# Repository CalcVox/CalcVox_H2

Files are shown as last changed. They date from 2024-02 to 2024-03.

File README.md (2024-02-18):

# CalcVox H2 Schematics and PCB Files

[View in Browser](https://kicanvas.org/?github=https://github.com/CalcVox/CalcVox_H2)

This is part of the [CalcVox](https://calcvox.org) Project. I am using KiCAD for these but I have included images below. 

I am trying to make these accessible but am struggling. If you know how to please open an issue.

## Parts

* [Teensy 4.1](https://www.pjrc.com/store/teensy41.html)
* [Seed Studio XIAO ESP32S3](https://www.seeedstudio.com/XIAO-ESP32S3-p-5627.html)
* [Adafruit UDA1334A I2S DAC (using a knockoff from amazon)](https://www.amazon.com/AITRIP-CJMCU-1334-UDA1334A-Decoder-Arduino/dp/B09DG21C7G)
* [Adafruit MiniBoost](https://www.adafruit.com/product/4654)
* [Rotary Encoder](https://www.sparkfun.com/products/9117)
* [Speaker (can use any)](https://www.adafruit.com/product/1891)
* 102AH 2.1mm Barrel Jack
* 3524N 3.5mm Audio Jack
* Piezo Buzzer
* Standard footprint buttons
* Various resistors
* Diodes

## Schematic

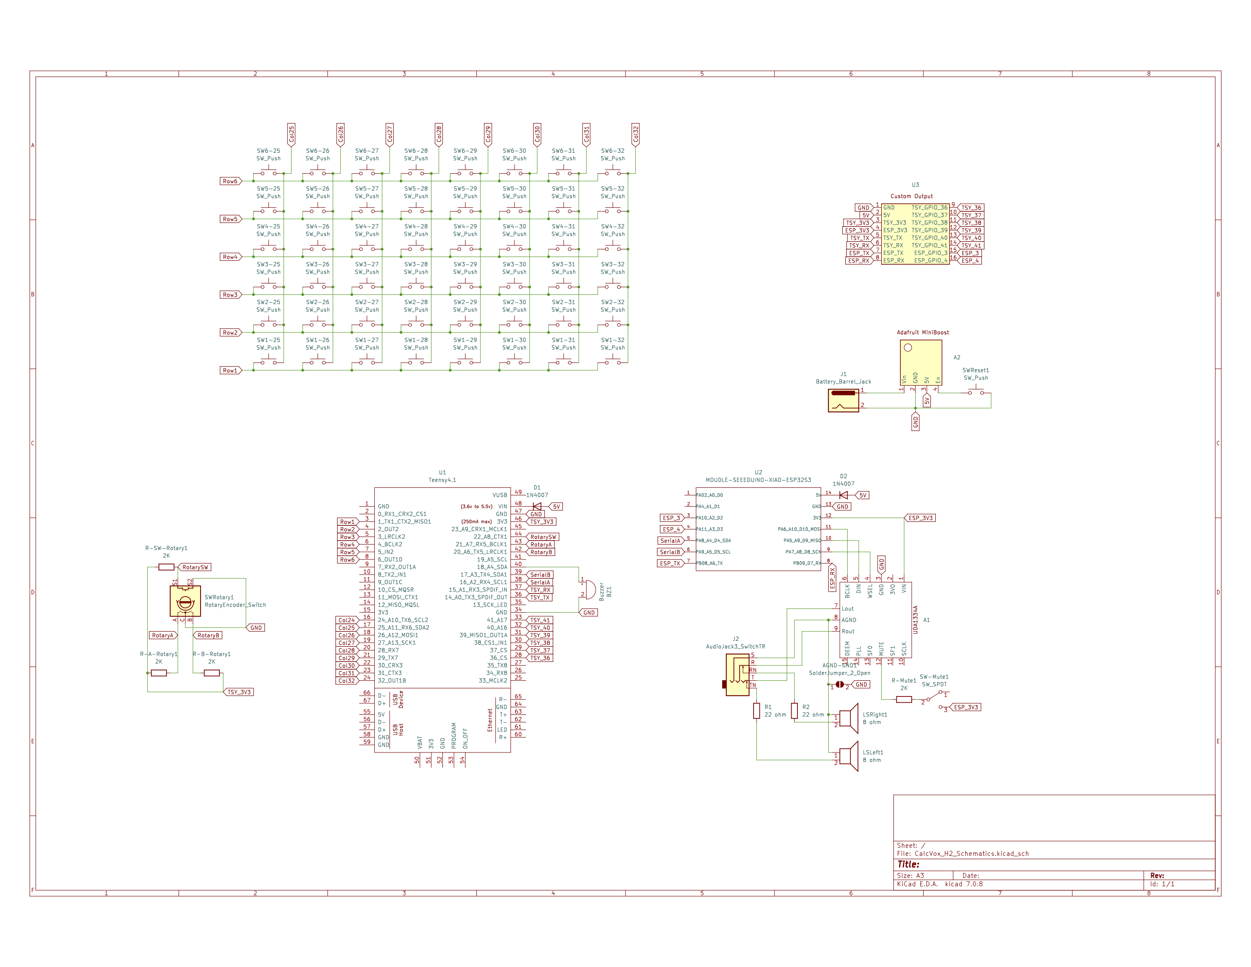
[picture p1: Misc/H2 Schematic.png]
H2 Schematic


## PCB

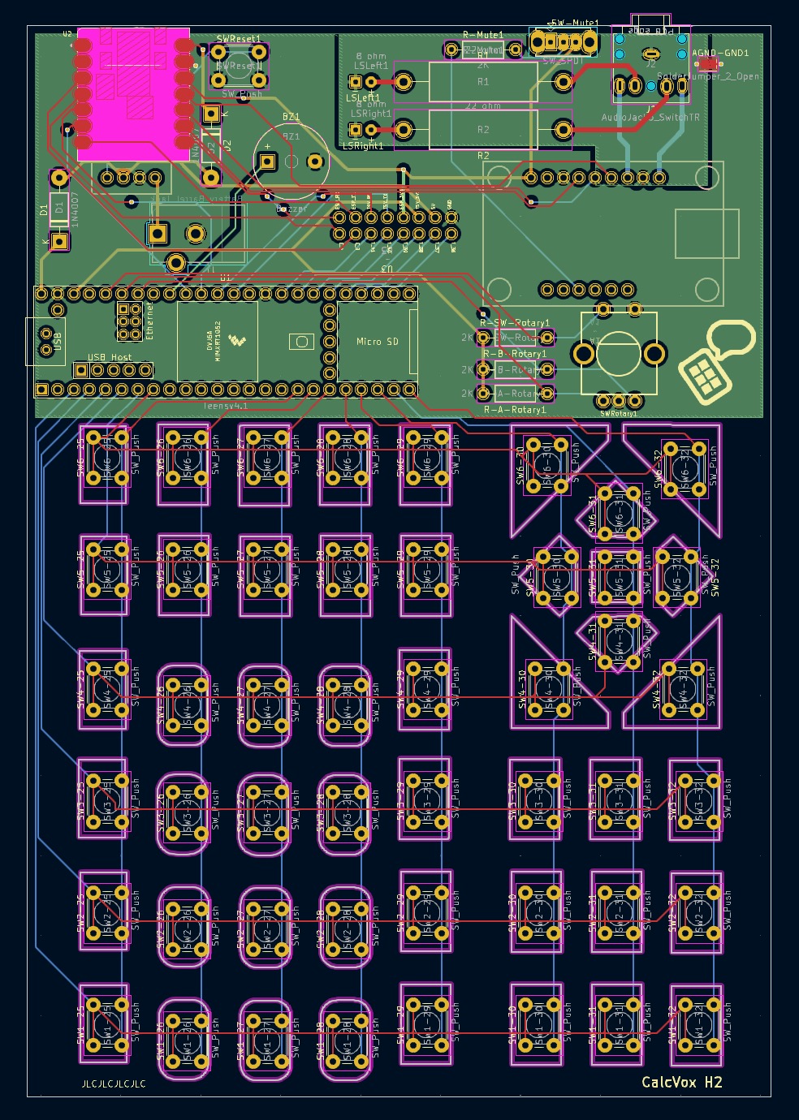
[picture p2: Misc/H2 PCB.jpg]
H2 PCB


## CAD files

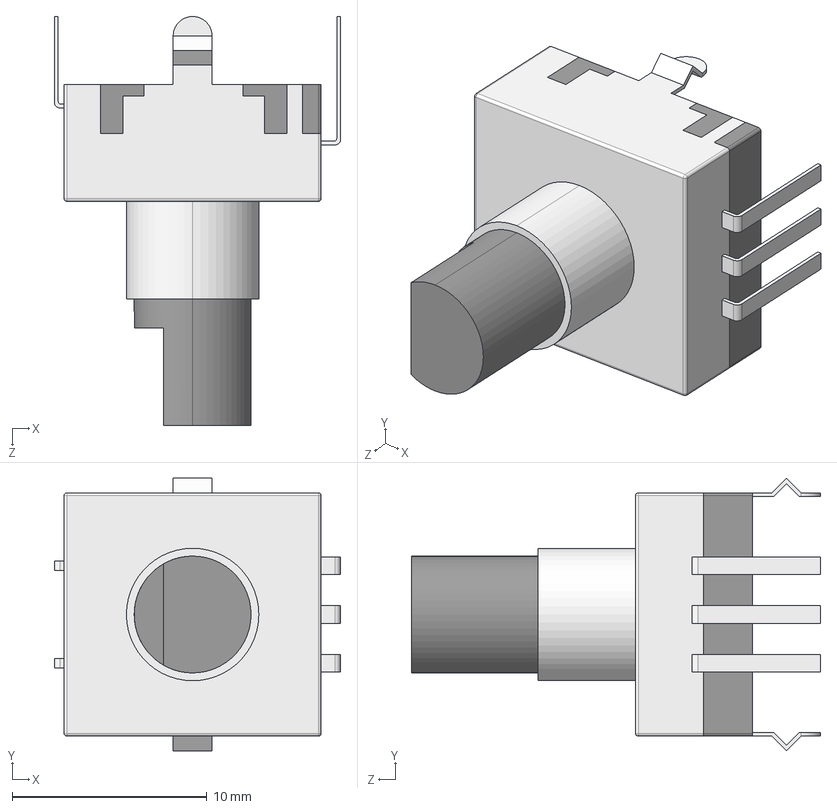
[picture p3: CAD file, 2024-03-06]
RE130F-41-175F-12P.stp
14.7 x 14.0 x 21.0 mm

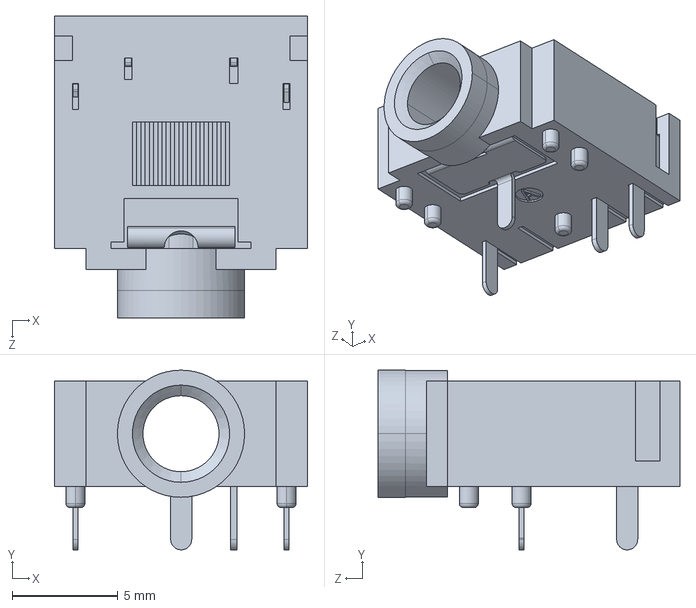
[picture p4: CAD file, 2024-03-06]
CUI_DEVICES_SJ1-3524N.step
12.0 x 8.51 x 14.3 mm

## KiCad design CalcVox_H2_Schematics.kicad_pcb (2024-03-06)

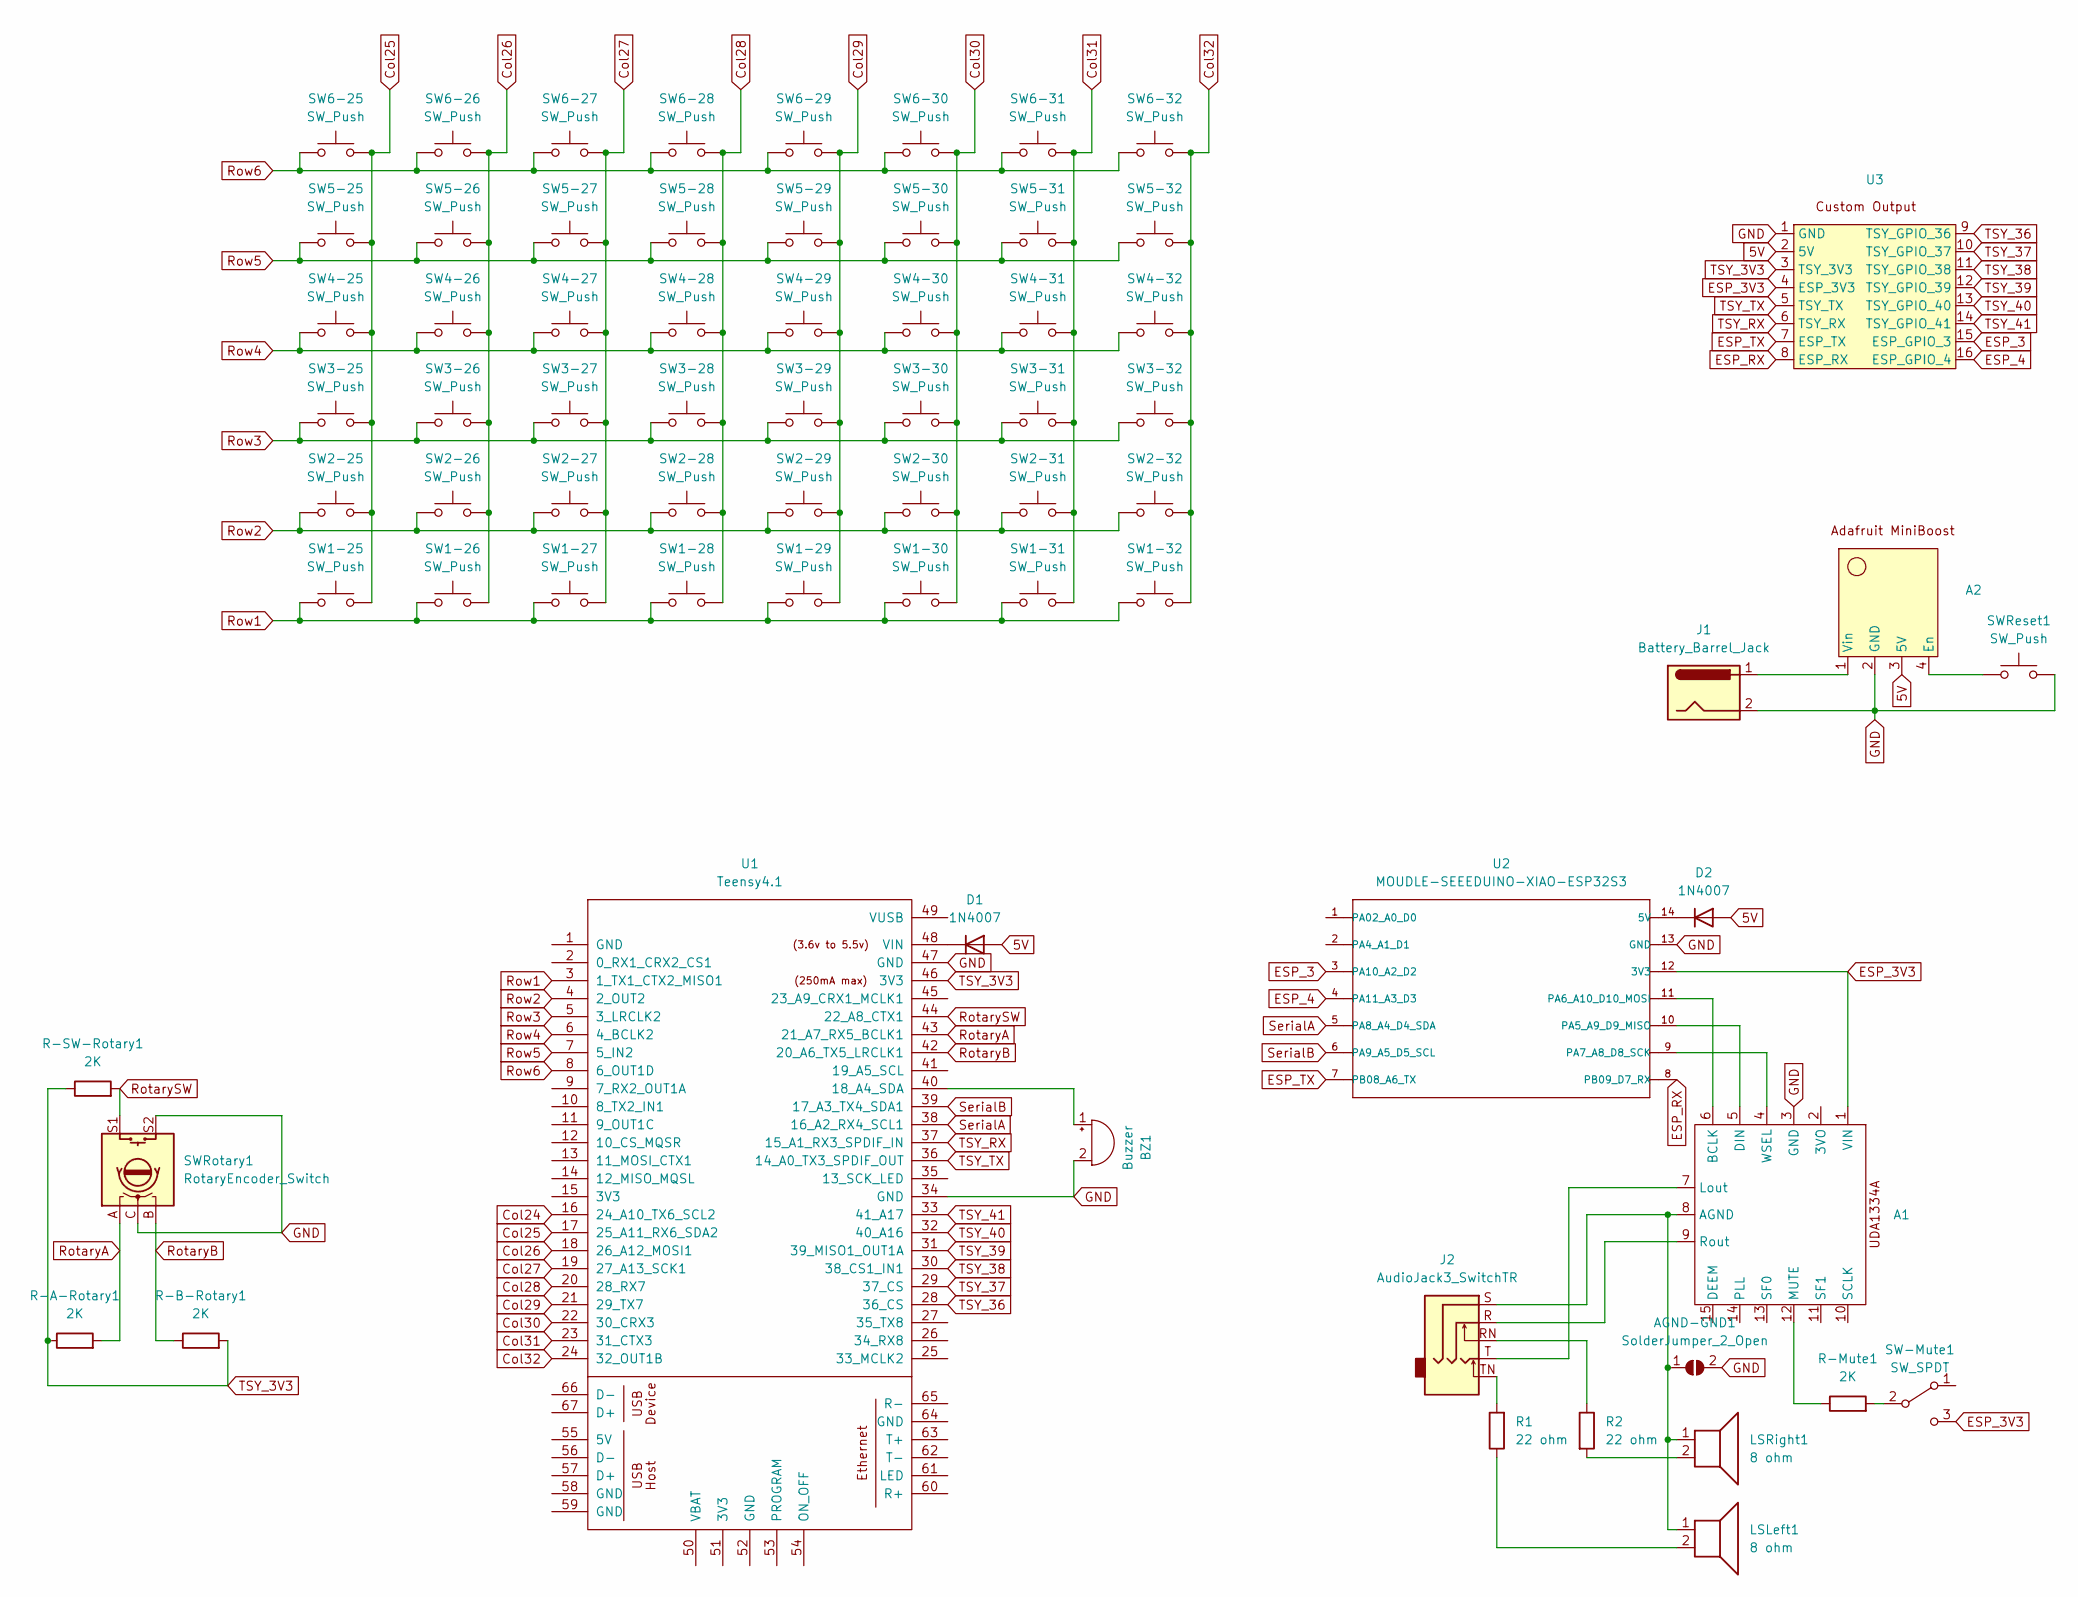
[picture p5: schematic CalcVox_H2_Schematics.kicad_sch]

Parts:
A1: Adafruit UDA1334A I2S Stereo DAC
A2: Adafruit MiniBost
AGND-GND1: SolderJumper_2_Open; SolderJumper-2_P1.3mm_Open_TrianglePad1.0x1.5mm
BZ1: Buzzer; Buzzer_12x9.5RM7.6
D1, D2: 1N4007; D_DO-41_SOD81_P10.16mm_Horizontal
J1: Battery_Barrel_Jack; BarrelJack_CUI_PJ-102AH_Horizontal
J2: AudioJack3_SwitchTR; Jack_3.5mm_CUI_SJ1-3524N_Horizontal
LSLeft1: 8 ohm; Speaker Hole
LSRight1: 8 ohm; Speaker Hole
R1, R2: 22 ohm; R_Axial_DIN0617_L17.0mm_D6.0mm_P25.40mm_Horizontal
R-A-Rotary1: 2K; R_Axial_DIN0207_L6.3mm_D2.5mm_P10.16mm_Horizontal
R-B-Rotary1: 2K; R_Axial_DIN0207_L6.3mm_D2.5mm_P10.16mm_Horizontal
R-Mute1: 2K; R_Axial_DIN0207_L6.3mm_D2.5mm_P10.16mm_Horizontal
R-SW-Rotary1: 2K; R_Axial_DIN0207_L6.3mm_D2.5mm_P10.16mm_Horizontal
SW1-25, SW1-26, SW1-27, SW1-28, SW1-29, SW1-30, SW1-31, SW1-32, SW2-25, SW2-26, SW2-27, SW2-28, SW2-29, SW2-30, SW2-31, SW2-32, SW3-25, SW3-26, SW3-27, SW3-28, SW3-29, SW3-30, SW3-31, SW3-32, SW4-25, SW4-26, SW4-27, SW4-28, SW4-29, SW4-30, SW4-31, SW4-32, SW5-25, SW5-26, SW5-27, SW5-28, SW5-29, SW5-30, SW5-31, SW5-32, SW6-25, SW6-26, SW6-27, SW6-28, SW6-29, SW6-30, SW6-31, SW6-32: SW_Push; SW_PUSH_6mm_H9.5mm
SW-Mute1: SW_SPDT; SW_Slide_1P2T_CK_OS102011MS2Q
SWReset1: SW_Push; SW_PUSH_6mm_H9.5mm
SWRotary1: RotaryEncoder_Switch; SF-ROTARY-ENCODER
U1: Teensy4.1; Teensy41
U2: MOUDLE-SEEEDUINO-XIAO-ESP32S3; MOUDLE14P-SMD-2.54-21X17.8MM
U3: Custom Output

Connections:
5V: A2.3 (5V), D1.2 (A), D2.2 (A), U3.2 (5V)
Col24: U1.16 (24_A10_TX6_SCL2)
Col25: SW1-25.2, SW2-25.2, SW3-25.2, SW4-25.2, SW5-25.2, SW6-25.2, U1.17 (25_A11_RX6_SDA2)
Col26: SW1-26.2, SW2-26.2, SW3-26.2, SW4-26.2, SW5-26.2, SW6-26.2, U1.18 (26_A12_MOSI1)
Col27: SW1-27.2, SW2-27.2, SW3-27.2, SW4-27.2, SW5-27.2, SW6-27.2, U1.19 (27_A13_SCK1)
Col28: SW1-28.2, SW2-28.2, SW3-28.2, SW4-28.2, SW5-28.2, SW6-28.2, U1.20 (28_RX7)
Col29: SW1-29.2, SW2-29.2, SW3-29.2, SW4-29.2, SW5-29.2, SW6-29.2, U1.21 (29_TX7)
Col30: SW1-30.2, SW2-30.2, SW3-30.2, SW4-30.2, SW5-30.2, SW6-30.2, U1.22 (30_CRX3)
Col31: SW1-31.2, SW2-31.2, SW3-31.2, SW4-31.2, SW5-31.2, SW6-31.2, U1.23 (31_CTX3)
Col32: SW1-32.2, SW2-32.2, SW3-32.2, SW4-32.2, SW5-32.2, SW6-32.2, U1.24 (32_OUT1B)
ESP_3: U2.3 (PA10_A2_D2), U3.15 (ESP_GPIO_3)
ESP_3V3: A1.1 (VIN), SW-Mute1.3 (C), U2.12 (3V3), U3.4 (ESP_3V3)
ESP_4: U2.4 (PA11_A3_D3), U3.16 (ESP_GPIO_4)
ESP_RX: U2.8 (PB09_D7_RX), U3.8 (ESP_RX)
ESP_TX: U2.7 (PB08_A6_TX), U3.7 (ESP_TX)
GND: A1.3 (GND), A2.2 (GND), AGND-GND1.2 (B), BZ1.2 (+), J1.2, SWReset1.2, SWRotary1.C, SWRotary1.S2, U1.34 (GND), U1.47 (GND), U2.13 (GND), U3.1 (GND)
unnamed: A1.8 (AGND), AGND-GND1.1 (A), J2.S, LSLeft1.1, LSRight1.1
unnamed: A1.6 (BCLK), U2.11 (PA6_A10_D10_MOSI)
unnamed: A1.5 (DIN), U2.10 (PA5_A9_D9_MISO)
unnamed: A1.7 (Lout), J2.T
unnamed: A1.12 (MUTE), R-Mute1.1
unnamed: A1.9 (Rout), J2.R
unnamed: A1.4 (WSEL), U2.9 (PA7_A8_D8_SCK)
unnamed: A2.4 (En), SWReset1.1
unnamed: A2.1 (Vin), J1.1
unnamed: BZ1.1 (-), U1.40 (18_A4_SDA)
unnamed: D1.1 (K), U1.48 (VIN)
unnamed: D2.1 (K), U2.14 (5V)
unnamed: J2.RN, R2.1
unnamed: J2.TN, R1.2
unnamed: LSLeft1.2, R1.1
unnamed: LSRight1.2, R2.2
unnamed: R-Mute1.2, SW-Mute1.2 (B)
RotaryA: R-A-Rotary1.2, SWRotary1.A, U1.43 (21_A7_RX5_BCLK1)
RotaryB: R-B-Rotary1.1, SWRotary1.B, U1.42 (20_A6_TX5_LRCLK1)
RotarySW: R-SW-Rotary1.2, SWRotary1.S1, U1.44 (22_A8_CTX1)
Row1: SW1-25.1, SW1-26.1, SW1-27.1, SW1-28.1, SW1-29.1, SW1-30.1, SW1-31.1, SW1-32.1, U1.3 (1_TX1_CTX2_MISO1)
Row2: SW2-25.1, SW2-26.1, SW2-27.1, SW2-28.1, SW2-29.1, SW2-30.1, SW2-31.1, SW2-32.1, U1.4 (2_OUT2)
Row3: SW3-25.1, SW3-26.1, SW3-27.1, SW3-28.1, SW3-29.1, SW3-30.1, SW3-31.1, SW3-32.1, U1.5 (3_LRCLK2)
Row4: SW4-25.1, SW4-26.1, SW4-27.1, SW4-28.1, SW4-29.1, SW4-30.1, SW4-31.1, SW4-32.1, U1.6 (4_BCLK2)
Row5: SW5-25.1, SW5-26.1, SW5-27.1, SW5-28.1, SW5-29.1, SW5-30.1, SW5-31.1, SW5-32.1, U1.7 (5_IN2)
Row6: SW6-25.1, SW6-26.1, SW6-27.1, SW6-28.1, SW6-29.1, SW6-30.1, SW6-31.1, SW6-32.1, U1.8 (6_OUT1D)
SerialA: U1.38 (16_A2_RX4_SCL1), U2.5 (PA8_A4_D4_SDA)
SerialB: U1.39 (17_A3_TX4_SDA1), U2.6 (PA9_A5_D5_SCL)
TSY_3V3: R-A-Rotary1.1, R-B-Rotary1.2, R-SW-Rotary1.1, U1.46 (3V3), U3.3 (TSY_3V3)
TSY_36: U1.28 (36_CS), U3.9 (TSY_GPIO_36)
TSY_37: U1.29 (37_CS), U3.10 (TSY_GPIO_37)
TSY_38: U1.30 (38_CS1_IN1), U3.11 (TSY_GPIO_38)
TSY_39: U1.31 (39_MISO1_OUT1A), U3.12 (TSY_GPIO_39)
TSY_40: U1.32 (40_A16), U3.13 (TSY_GPIO_40)
TSY_41: U1.33 (41_A17), U3.14 (TSY_GPIO_41)
TSY_RX: U1.37 (15_A1_RX3_SPDIF_IN), U3.6 (TSY_RX)
TSY_TX: U1.36 (14_A0_TX3_SPDIF_OUT), U3.5 (TSY_TX)

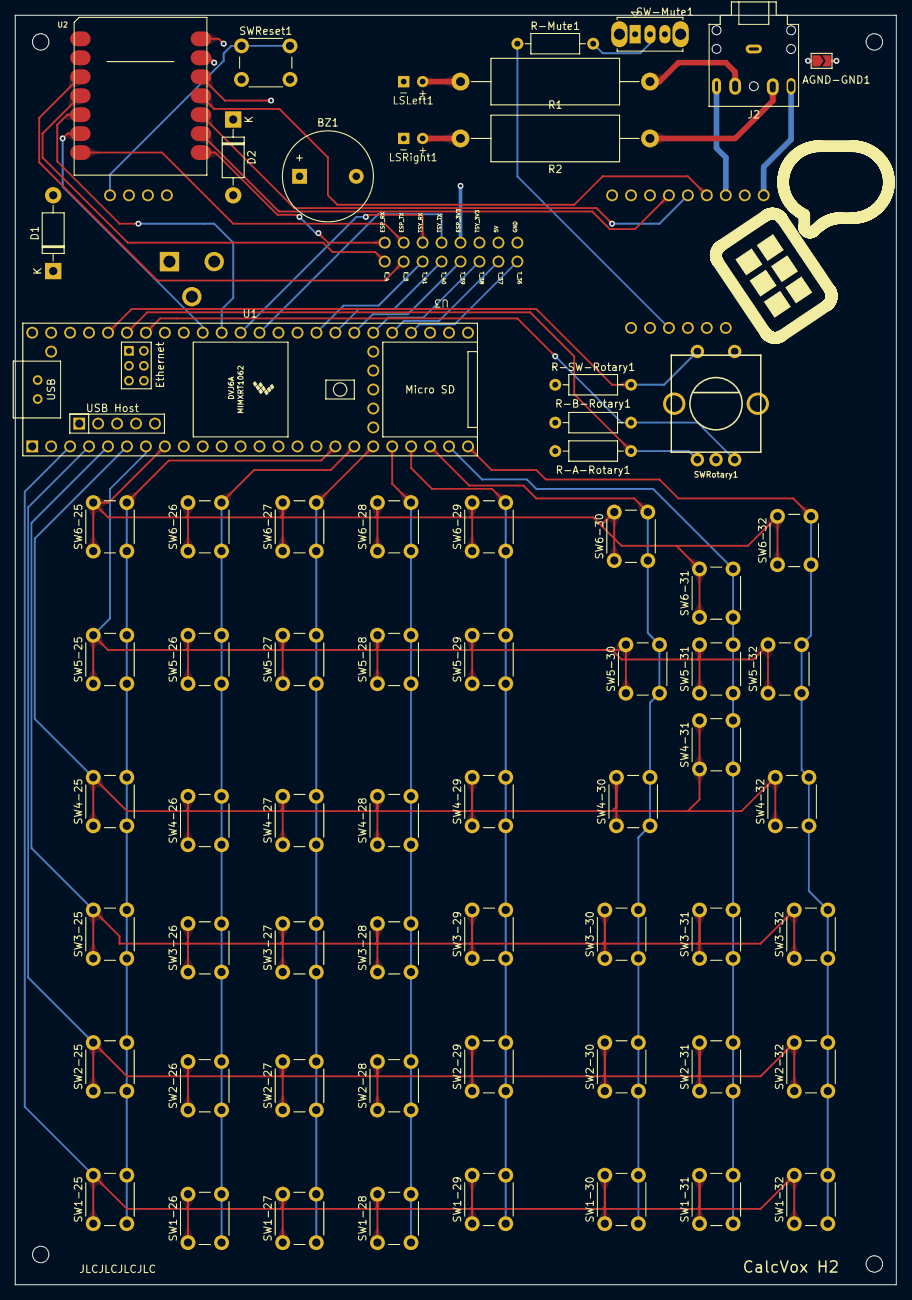
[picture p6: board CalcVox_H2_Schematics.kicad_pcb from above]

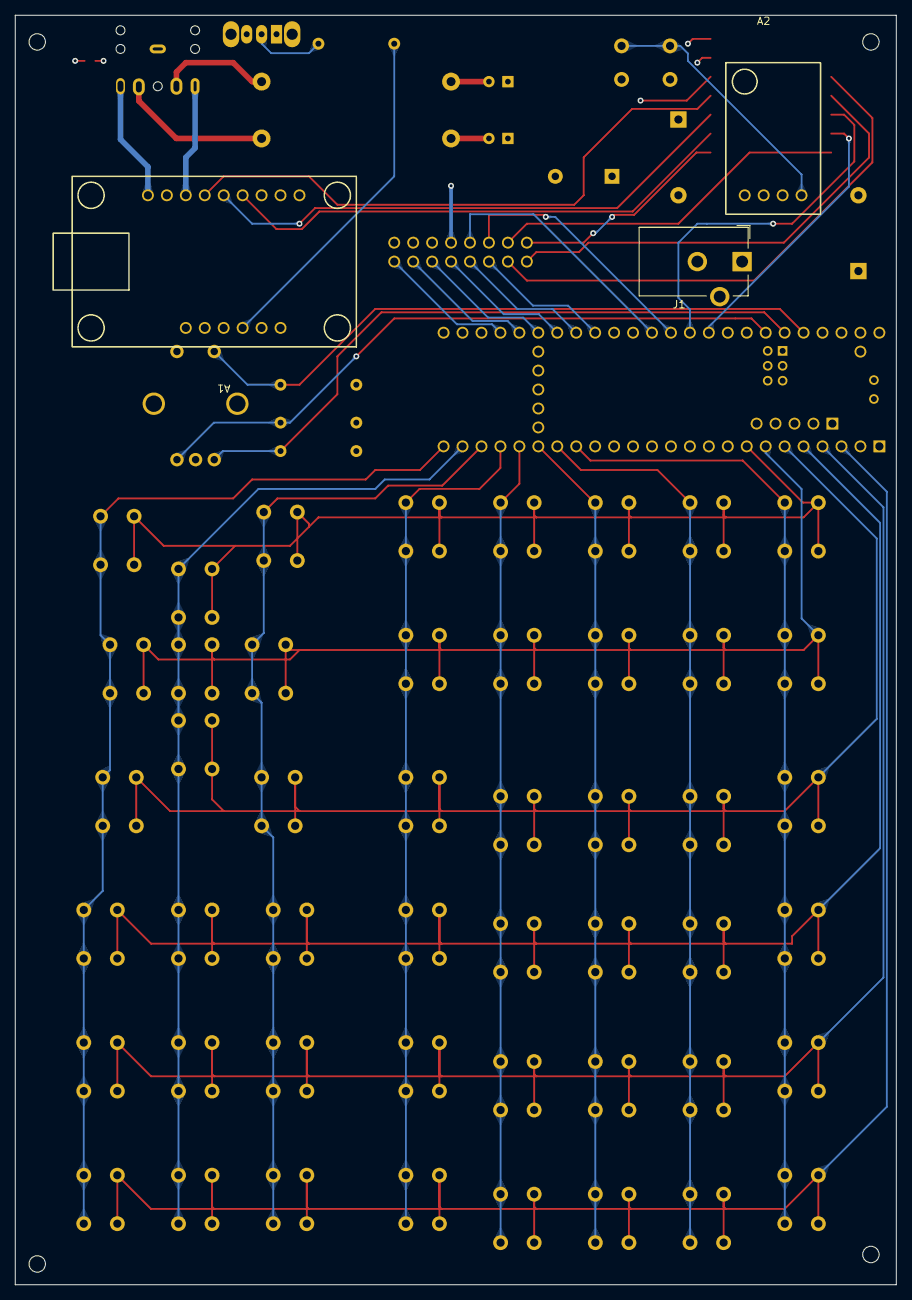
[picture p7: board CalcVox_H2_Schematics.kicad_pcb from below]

Board: 4 copper layers, 118.1 x 170.2 mm, 70 parts (3 on the bottom side), 52 nets.

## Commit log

2024-02-14 Small change to move board up
    [CalcVox_H2_Schematics.kicad_pcb]
2024-02-15 added readme
    [CalcVox_H2_Schematics.kicad_pcb, CalcVox_H2_Schematics.kicad_sch]
2024-03-06 Added 3d models and fixed small mistakes
    [CUI_DEVICES_SJ1-3524N.step, CalcVox_H2_Schematics.kicad_pcb, CalcVox_H2_Schematics.kicad_sch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]
2024-03-08 updated with feedback
    [CalcVox_H2_Schematics.kicad_sch]
